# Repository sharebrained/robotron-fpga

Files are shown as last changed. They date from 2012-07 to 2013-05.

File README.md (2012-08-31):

robotron-fpga
=============

An implementation of the classic Robotron: 2084 video arcade game from 1982.
Both the sound board and CPU/interface boards are implemented, but are in
separate sub-projects at the moment. The CPU/interface implementation relies
on a Motorola MC6809E processor attached to the FPGA board via an adapter
board design that is part of this project.

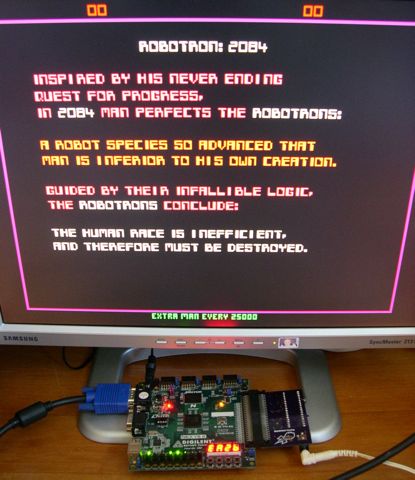
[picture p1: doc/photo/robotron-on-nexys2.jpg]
robotron-cpu on NEXYS2 FPGA board


The goal is to have a complete Robotron: 2084 game implemented in a single,
compact, inexpensive FPGA board which includes the necessary peripherals:
video and sound outputs, joysticks interface, and coin/player buttons.

Status
======

The CPU/interface and sound boards are implemented as separate projects.
Both appear to function well.

The MC6809E breakout board has been fabricated, but has some design issues
that need to be addressed. The primary issue is the lack of pull-up/-down
resistors on key MC6809E signals, to keep the processor in a RESET state
until the FPGA board is ready to work with the MC6809E. I also screwed up
and put the NEXYS2 connector on the "bottom side" of the board. Smooth!

Documentation
=============

These documents served me well during development of this project.

[Sean Riddle](http://seanriddle.com/) - Williams arcade machine information,
including Robotron: 2084.

* [Hardware overview](http://seanriddle.com/willhard.html)
* [Memory map](http://seanriddle.com/memmap.gif)
* [Processor and video timing](http://seanriddle.com/timing.html)
* [BLTter description and test code](http://seanriddle.com/blittest.html)

[Robotron-2084](http://www.robotron-2084.co.uk/) - Williams arcade machine
official documentation.

* [Robotron schematics and instruction manuals](http://www.robotron-2084.co.uk/manualsrobotron.html)
* [Defender "later series" theory of operation](http://www.robotron-2084.co.uk/manualsdefender.html),
    interesting because the Robotron and Defender hardware is quite
    similar.
    
Documentation for various ICs in the original Robotron: 2084 machine.

* [MC6809E microprocessor datasheet](http://www.classiccmp.org/dunfield/r/6809e.pdf)
* [MC6809E microprocessor programming manual](http://www.classiccmp.org/dunfield/r/6809prog.pdf)
* [DM9316 Synchronous 4-Bit Binary Counter](http://www.ti.com/product/dm9316)
* National Semiconductor(?) DM7489 64-bit random access read/write memory
    (no good reference)
* [Harris HM-7641 512 x 8 PROM](http://www.bitsavers.org/pdf/harris/_dataBooks/1978_Harris_Memory_Vol1.pdf) (page 2-35)
* [Harris HM-6514 1024 x 4 CMOS RAM](http://www.bitsavers.org/pdf/harris/_dataBooks/1978_Harris_Memory_Vol1.pdf) (page 3-49)
* [Mostek MK4116 16,384 x 1 bit dynamic RAM](http://hardware.speccy.org/datasheet/MK4116.pdf)
* [Signetics 8T97 hex buffer](http://www.bitsavers.org/pdf/signetics/_dataBooks/1977_Bipolar_Microprocessor.pdf) (page 96)
* [Various 74-series logic ICs](http://www.ti.com/lsds/ti/logic/home_overview.page)
    
[Digilent](http://www.digilentinc.com/) - FPGA development boards and 
accessories.

* [NEXYS2 FPGA development board](http://digilentinc.com/Products/Detail.cfm?NavPath=2,400,789&Prod=NEXYS2)

[Xilinx](http://www.xilinx.com/) - FPGA silicon and tools vendor.

* [Spartan-3E documentation](http://www.xilinx.com/support/documentation/spartan-3e.htm)

Requirements
============

* Digilent NEXYS2 Spartan-3E FPGA development board.

    This is the board I've done my development on, and is a good choice
    because it has plenty of inputs, a VGA output connector, many switches
    and LEDs, and enough onboard RAM and flash to meet the game's memory
    needs.

* Williams Robotron: 2084 ROM binary files:

    These files are often used with MAME, the arcade emulator. CPU board
    ROM files are named "robotron.sb?", where "?" is "1" through "9" and
    "a" through "c". The sound board ROM file is named "robotron.snd".

* Python 2.7:

    Used to transform ROM and PROM files into VHDL files.

* Xilinx ISE WebPack 13.4:

    For compiling VHDL and generating the bit file for the FPGA.

* Digilent Adept or other JTAG tool:

    For loading the bit file into FPGA board.

* VGA monitor:

    Video output is 31.25 kHz horizontal sync and 60 Hz vertical sync,
    which is compatible with VGA monitors. The output is line-doubled
    from the arcade game's original 15.625 kHz horizontal sync.

* RC lowpass filter:

    The PWM audio output from the FPGA needs filtering to sound reasonable,
    or an eight-bit DAC can be attached to the 8-bit audio output pins of
    the FPGA board.

Tools
=====

* make_rom_file.py:

    Translates a set of Robotron ROM board ROM files
    (like those you would use with the MAME arcade emulator) into a
    binary file that can be loaded into the flash device on the Digilent
    FPGA board.

* make_decoder_vhdl.py:

    Translates a decoder.4 or decoder.6 file (data
    dumped from decoder PROMs on the Robotron CPU board) into a VHDL
    file used by the robotron_cpu project.

* dac_out_wave.py:

    Translates the text file output of robotron_test.vhd
    into a WAV file that can be played.

* make_sound_rom.py:

    Produces rom_snd_blocks.vhd, containing VHDL ROM
    blocks, from the contents of a robotron.snd ROM file. The
    robotron.snd file is not provided due to copyright on the original
    ROM binaries produced by Williams. I happen to have a physical
    instance of the ROM board, so I'm in the clear. :-)

Contributing
============

Contributions are welcome!

Please respect Williams Electronics' copyright and do not post any VHDL
or .bit files containing their binary code.

License
=======

This hardware design is licensed under a
[Creative Commons Attribution-ShareAlike 3.0 Unported License]
(http://creativecommons.org/licenses/by-sa/3.0/).

The associated software is provided under the GNU Public License, 
version 3:

This project is free software: you can redistribute it and/or
modify it under the terms of the GNU General Public License as
published by the Free Software Foundation, either version 3 of the
License, or (at your option) any later version.

This project is distributed in the hope that it will be useful,
but WITHOUT ANY WARRANTY; without even the implied warranty of
MERCHANTABILITY or FITNESS FOR A PARTICULAR PURPOSE. See the GNU
General Public License for more details.

You should have received a copy of the GNU General Public License
along with this project. If not, see <http://www.gnu.org/licenses/>.

Contact
=======

Jared Boone <jared@sharebrained.com>

ShareBrained Technology, Inc.

<http://www.sharebrained.com/>

The latest version of this repository can be found at
https://github.com/sharebrained/robotron-fpga

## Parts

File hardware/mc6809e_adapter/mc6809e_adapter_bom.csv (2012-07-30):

Ref | Qty | Mfr | Mfr Part | Desc | Vendor | Vendor Part
J1 | 1 | Hirose | FX2-100S-1.27DS(71) | CONN RECEPT R/A 100POS 1.27MM | Digi-Key | H10644-ND
J2 | 1 | CUI | PJ-102A | CONN JACK POWER 2.1MM PCB | Digi-Key | CP-102A-ND
U1 | 1 | Motorola | MC6809EP | Microprocessor, 8bit CISC, 1MHz | Jameco | 43545
U1 (socket) | 1 | Assmann | AR40-HZL-TT-R | IC SOCKET MACH PIN ST 40POS TIN | Digi-Key | AE10018-ND
U2,3,4,5,6 | 5 | Texas Instruments | SN74LVC4245APW | IC BUS TRANSCEIVER 8BIT 24TSSOP | Digi-Key | 296-12183-1-ND
U7 | 1 | Texas Instruments | SN74LVC1G14DCK | IC SGL SCHMT-TRIG INVERT SC70-5 | Digi-Key | 296-11608-1-ND
U8 | 1 | Microchip | TC1262-5.0VDB | IC CMOS LDO 500MA 5.0V SOT223-3 | Digi-Key | TC1262-5.0VDB-ND
R1 | 1 | Yageo | RC0603FR-07220RL | RES 220 OHM 1/10W 1% 0603 SMD | Digi-Key | 311-220HRCT-ND
R2,3,4,5,6,7,8 | 7 | Yageo | RC0603FR-0710KL | RES 10.0K OHM 1/10W 1% 0603 SMD | Digi-Key | 311-10.0KHRCT-ND
C1,2,3,4,5,6,7,8,9,10,11 | 11 | Murata | GRM188R71C104KA01D | CAP CER 0.1UF 16V 10% X7R 0603 | Digi-Key | 490-1532-1-ND
C12 | 1 | Kemet | T491D476M010AT | CAP TANT 47UF 10V 20% 2917 | Digi-Key | 399-3796-1-ND
C13,14,15 | 2 | Kemet | C0805C475K8PACTU | CAP CER 4.7UF 10V 10% X5R 0805 | Digi-Key | 399-3133-1-ND
PCB | 1 | Laen |  | Two-layer service

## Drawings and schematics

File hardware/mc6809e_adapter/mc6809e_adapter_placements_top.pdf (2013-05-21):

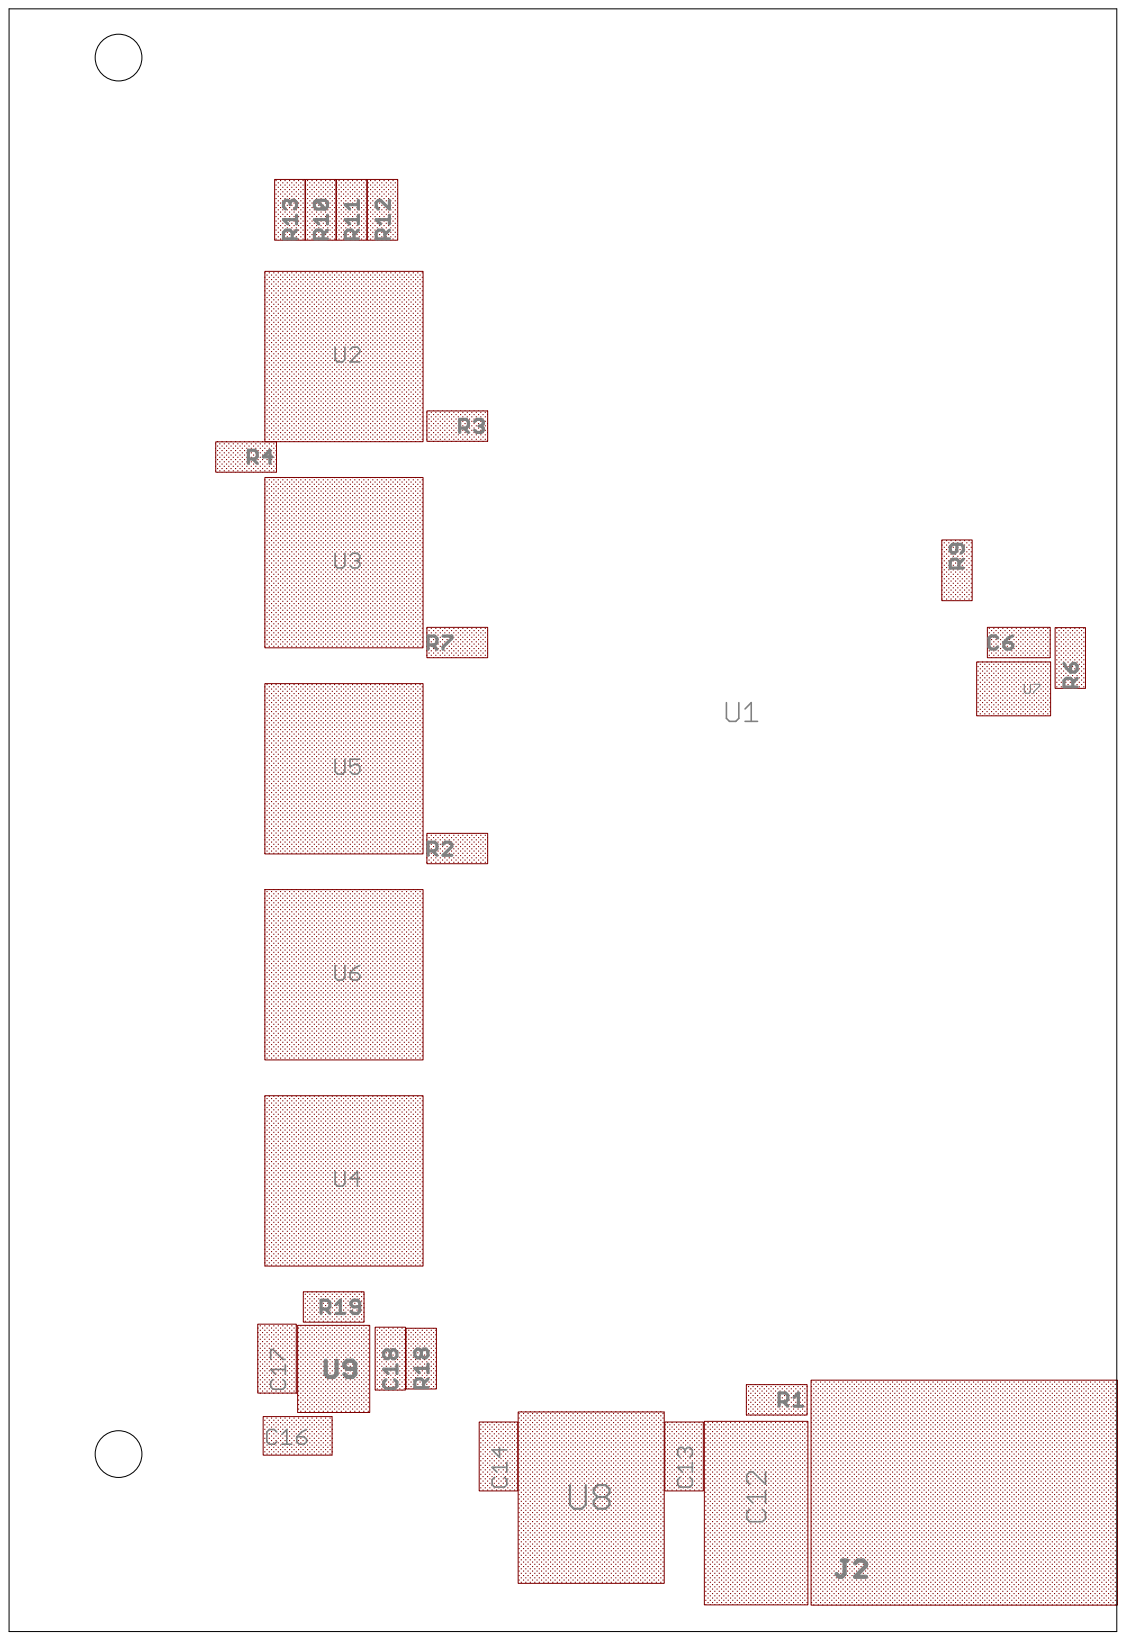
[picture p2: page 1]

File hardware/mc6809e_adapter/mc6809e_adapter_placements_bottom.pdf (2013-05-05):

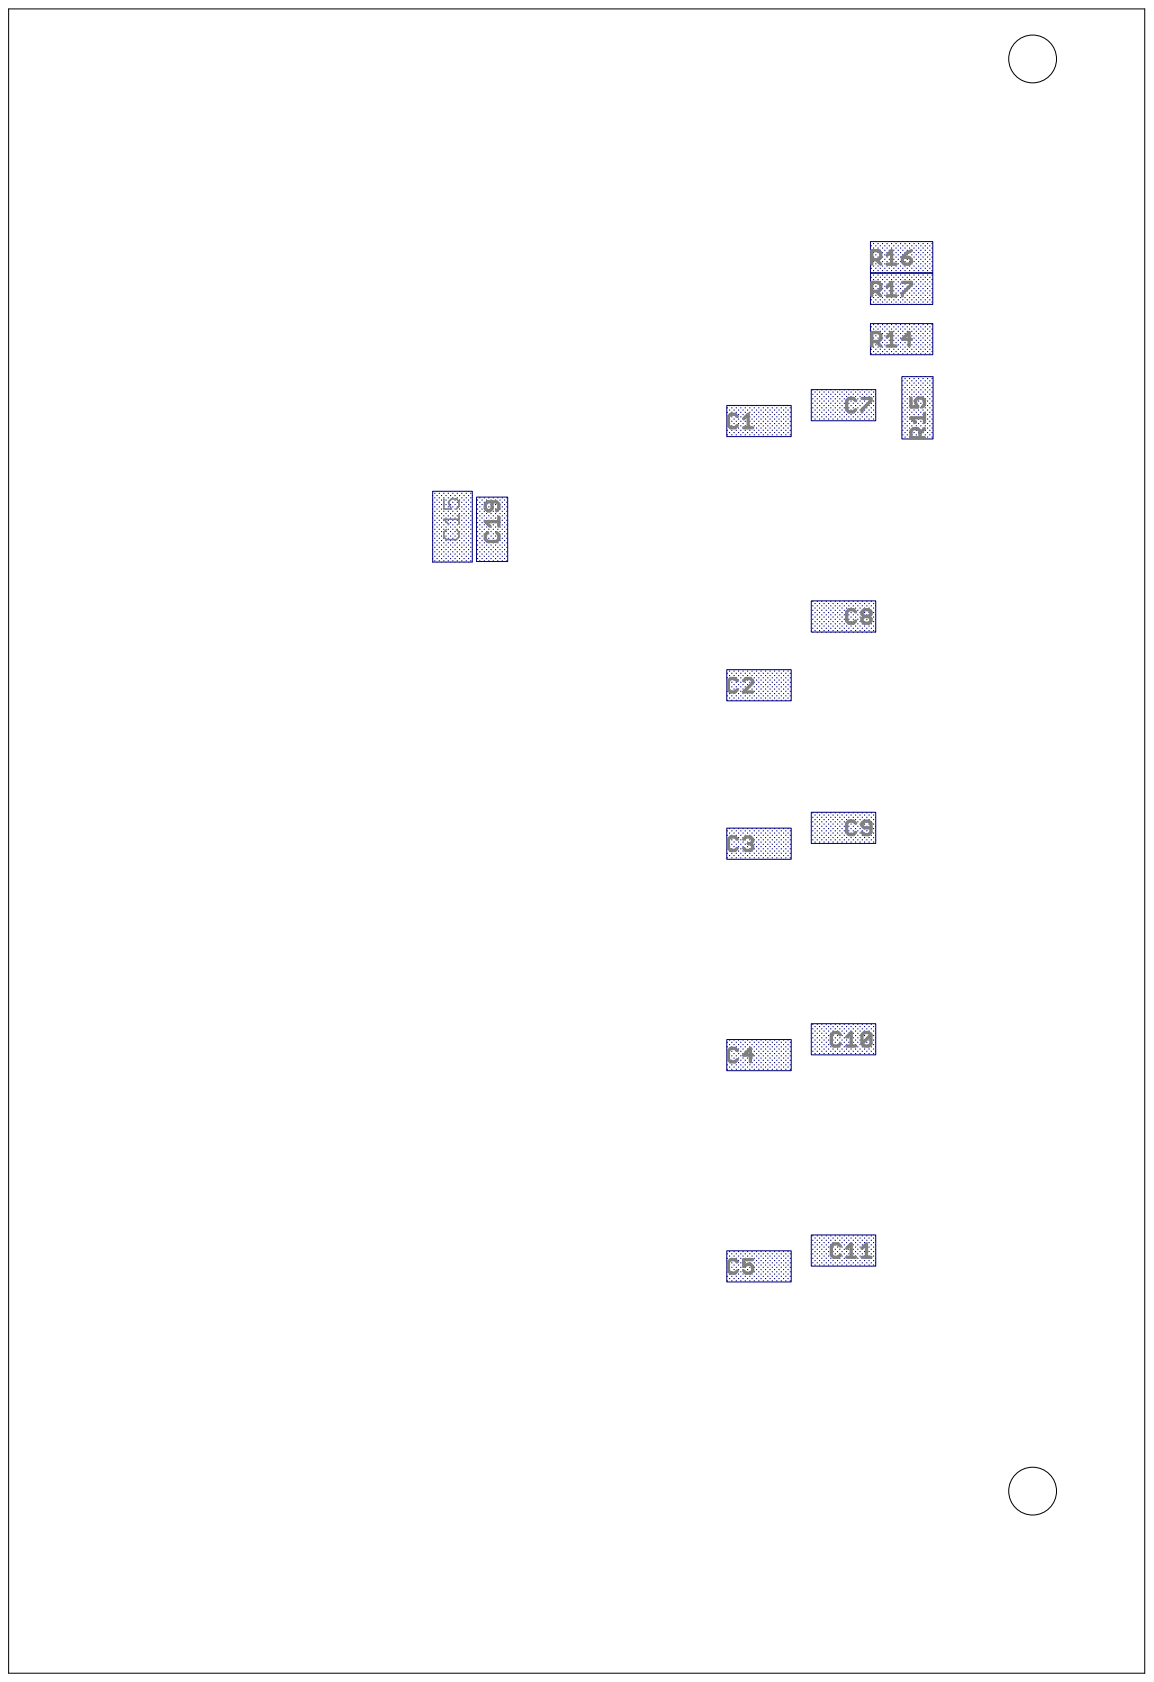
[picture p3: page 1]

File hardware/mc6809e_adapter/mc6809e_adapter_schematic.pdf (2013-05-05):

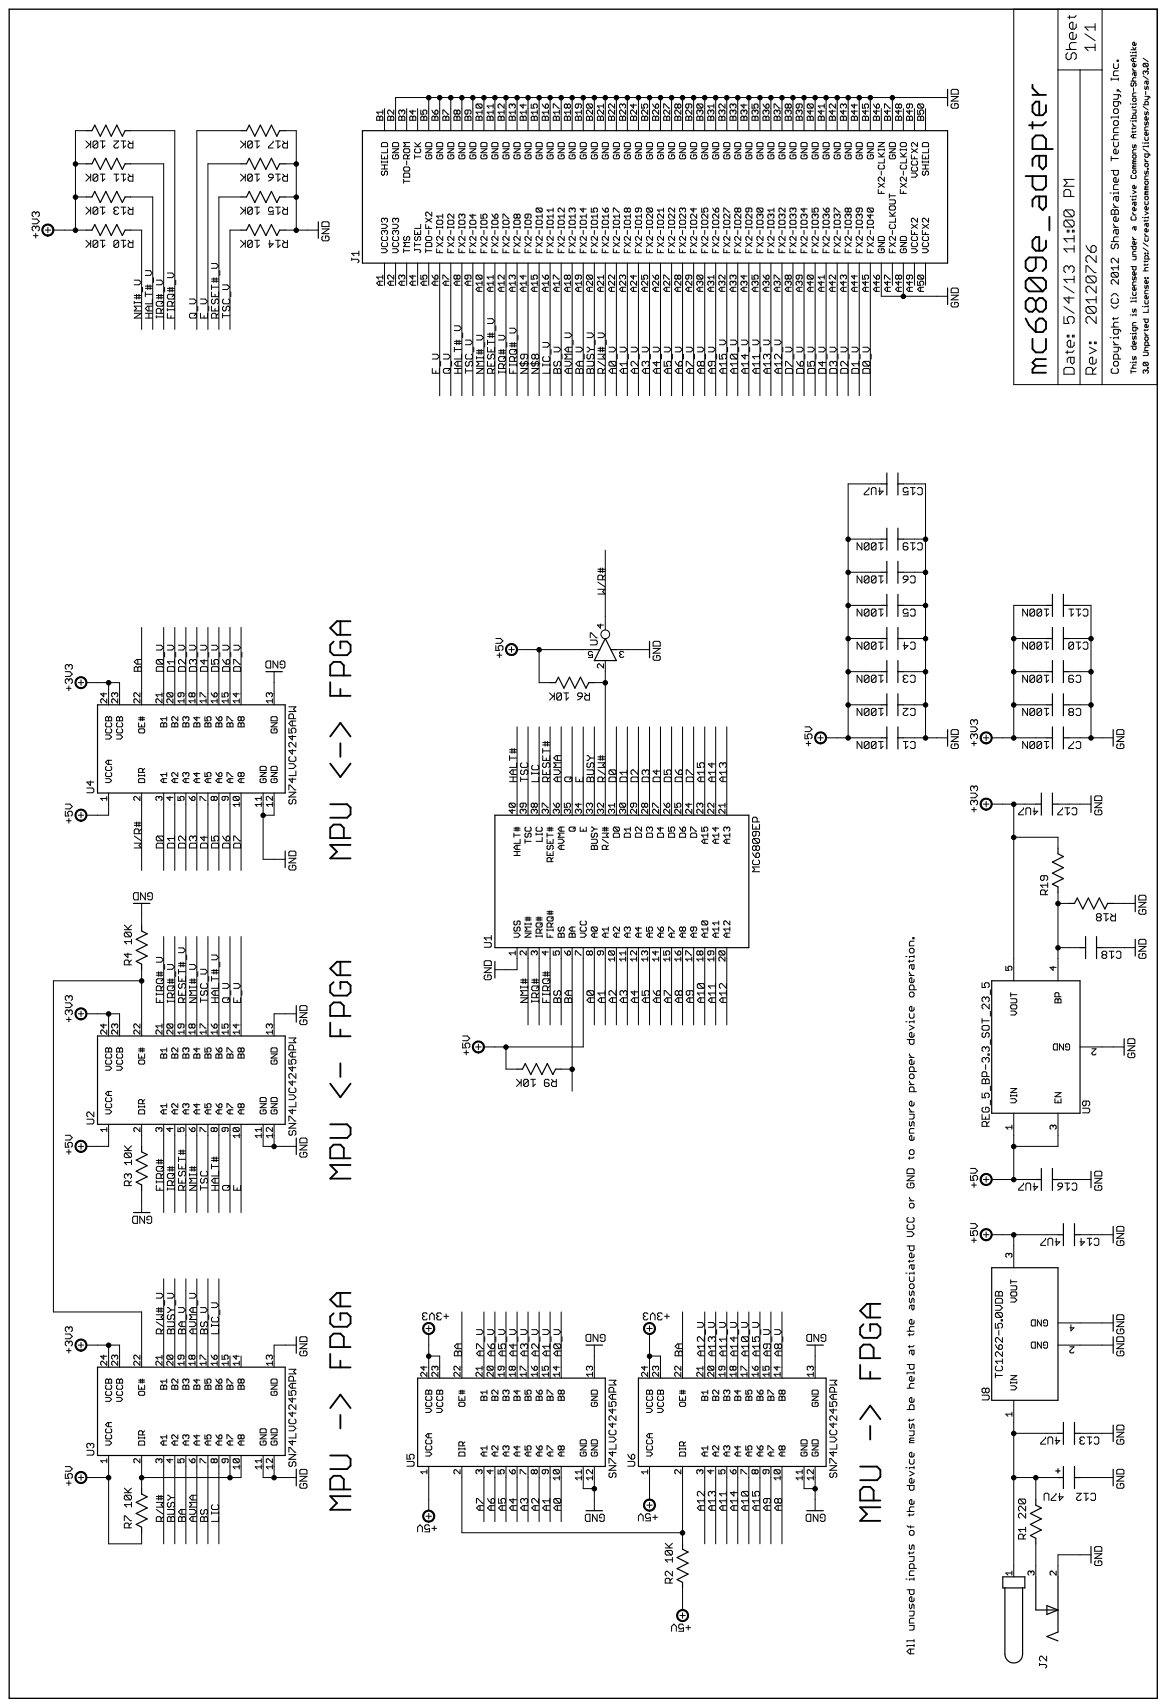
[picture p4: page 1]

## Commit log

2011-09-08 Initial commit for: - Xilinx Spartan-3 Starter Board - Digilent Nexys 2
    GPL3 License in place.
    Perfunctory README
    .gitignore prevents me from checking in Williams ROM binaries, and keeps the Xilinx ISE file-turds out of source control.
    The project builds a .bit file and executes on my Nexys 2, though behavior is a bit erratic. This may be due to poor VHDL coding practices on my part. This project was originally written on the Xilinx Spartan-3 Starter Board, which I no longer own. Everything *should* still work, however.
2012-07-30 Initial version of MC6809E-to-NEXYS2 FPGA board adapter. PCB is being fabbed, so design is as yet untested.
    One flaw I've already noticed: The FPGA board connector is on the wrong side of the board! This should be an easy revision for the next release. It may also be possible to very carefully modify rework the board to make this revision work -- power supply and ground traces on the A row will need to be cut and rewired. Not pretty, but probably doable.
    [mc6809e_adapter.brd, mc6809e_adapter.sch, mc6809e_adapter_bom.csv]
2012-08-30 Initial commit of robotron_cpu project, which implements the CPU, ROM, and interface boards of the Robotron: 2084 arcade game.
    At present, this is marginally functional. Video output (composite or VGA) is not done, interface signals are not pinned out on FPGA, and sound board is not implemented (see separate robotron_sound d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
2012-08-30 Tightened up BLT and MPU accesses to flash/RAM to only one 12MHz clock cycle. Making room for lots of video counter accesses to RAM.
2012-08-30 Amended: chunk confusion caused invalid (out-of-order) VHDL. Change LED numeric display clock to run from 12MHz system clock (instead of 50MHz external clock).
2012-08-30 Factor debug signals away from LED numeric display assignment.
2012-08-30 Cleaned up switch assignments for testing. Inverted switch inputs (inputs on machine are pulled up and grounded when switches are actuated).
2012-08-30 Added comment about NEXYS2 connector being on wrong side of PCB. Fixed "spelling" of NEXYS2 board.
2012-08-31 Add photo of Robotron game running on FPGA board and VGA monitor.
2012-08-31 Switch image URL to HTTPS, in case visitor loaded HTTPS GitHub URL.
2012-08-31 Added constraints for two Pmod connectors. Added PULLUP attribute to stand in for pull-ups on interface board. Added mapping of JA and JB ports to joystick pins (for a total of four joysticks -- two 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
2013-04-24 Factor out common sound module, for use by board/silicon-specific top module.
2013-05-05 Reworked schematic to allow easier pin-swapping. New board layout that is more representational of how the board plugs into the FPGA board. Hirose FX2 connector flipped to front side of board. Added 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
    [mc6809e_adapter.brd, mc6809e_adapter.sch]
2013-05-21 Updated FPGA .ucf to match new pinout from updated MC6809E adapter board (20130505).
